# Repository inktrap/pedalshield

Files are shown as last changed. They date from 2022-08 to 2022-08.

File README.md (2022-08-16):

# Pedalshield Due

I wanted "my own" overview of pedalshield resources, one that allows for collaboration and forks, and that is always available. So here we go.

## General

 - [electrosmash site](https://www.electrosmash.com/pedalshield)
 - the [most important topics](https://www.electrosmash.com/forum/software-pedalshield/233-best-pedalshield-due-topics) from the [electrosmash due forum](https://www.electrosmash.com/forum/pedalshield-due)
 - [howtos](https://www.electrosmash.com/forum/hardware-pedalshield/20-how-to-build-pedalshield-in-5-steps?lang=en)  ([pdf](https://www.electrosmash.com/media/kunena/attachments/44/How-to-Build-pedalSHIELD-DUE.pdf), [flickr](https://www.flickr.com/photos/electrosmash/sets/72157638250771595/), [youtube](
https://www.youtube.com/watch?v=0nAO9C56jZM))

## Hardware

Analysis

 - [hardware analysis](https://www.electrosmash.com/forum/hardware-pedalshield/166-hardware-analysis-of-pedalshield)
 - [circuit diagram](https://i.stack.imgur.com/7KS3T.png) → `circuit.png`
 - [input/output stages](https://www.electrosmash.com/forum/hardware-pedalshield/73-input-output-stages)

Parts

 - [BOM](https://www.electrosmash.com/media/kunena/attachments/44/BOM-pedalSHIELD.rar) (rar) `BOM-pedalSHIELD.rar` → `bom` and [alternatives](https://www.electrosmash.com/forum/hardware-pedalshield/17-pedalshield-bill-of-materials-and-alternatives)
 - [best options to power arduino due](http://www.electrosmash.com/forum/hardware-pedalshield/26-powering-arduino-due?lang=en)
 - [troubleshooting guide](http://www.electrosmash.com/forum/hardware-pedalshield/72-guide-to-troubleshoot-pedalshield?lang=en)

Files

 - [kicad schematics](https://www.electrosmash.com/forum/hardware-pedalshield/18-kicad-schematics-pedalshield) via `PedalShield-rev.E-nativefiles.zip` → `kicad`
 - [gerber files](https://www.electrosmash.com/media/kunena/attachments/631/pedalSHIELDGerberFIles.rar) (rar) `pedalSHIELDGerberFIles.rar` → `gerber`
 - [pcb transfers](http://www.electrosmash.com/forum/hardware-pedalshield/82-pedalshield-pcb-transfers?lang=en)

## Software

 - [how to program pedalshield](http://www.electrosmash.com/forum/software-pedalshield/21-how-to-start-programming-pedalshield?lang=en)
 - effects: [bitcrusher](http://www.electrosmash.com/forum/software-pedalshield/156-bitcrusher-sample-rate-reducer-with-lfo?lang=en#592), [schroeder's reverb](http://www.electrosmash.com/forum/software-pedalshield/175-schoreder-s-reverb?lang=en), [Chorus, Chorus Dattorro, Echo, Flanger, Vibrato, Fuzz, Reverb Schroeder, Tremolo](http://www.electrosmash.com/forum/software-pedalshield/133-several-codes-based-on-pedalshield-library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) all by AndrewHPAvei
 - [all pedals](https://www.open-electronics.org/wp-content/uploads/2014/04/pedalSHIELD-all-pedals.rar) (rar) `pedalSHIELD-all-pedals.rar` → `pedals`

## Misc

 - [covers and cases on thingiverse](https://www.thingiverse.com/search?q=pedalshield&sa=&dwh=485aa2707f64633&type=things&sort=relevant), [printed cover](https://www.thingiverse.com/thing:210541) → `covers`. Laser cut covers are in the electrosmash shop as part of the kit.
 - [op amp book](http://www.ee.nmt.edu/~anders/courses/ee322s10/op-amp-slod006a.pdf) (pdf) `op-amp-slod006a.pdf`
 - connect a [screen](http://www.electrosmash.com/forum/hardware-pedalshield/94-mounting-an-oled-screen-on-my-pedalshield?lang=en), a [microphone](http://www.electrosmash.com/forum/hardware-pedalshield/39-connecting-a-microphone-to-pedalshield?lang=en), … also mods for a [bass guitar](http://www.electrosmash.com/forum/hardware-pedalshield/79-guitar-pedal-modification-pedalshield-for-bass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) … these are just copied from the [important topics](https://www.electrosmash.com/forum/software-pedalshield/233-best-pedalshield-due-topics) linked at the beginning.

# License

Published under the [Attribution-NonCommercial 3.0 Unported (CC BY-NC 3.0)](https://creativecommons.org/licenses/by-nc/3.0/) license. Some 
[rights are reserved](https://www.electrosmash.com/rights). Currently all of this can be found through [the links mentioned here](https://www.electrosmash.com/pedalshield) anyways.

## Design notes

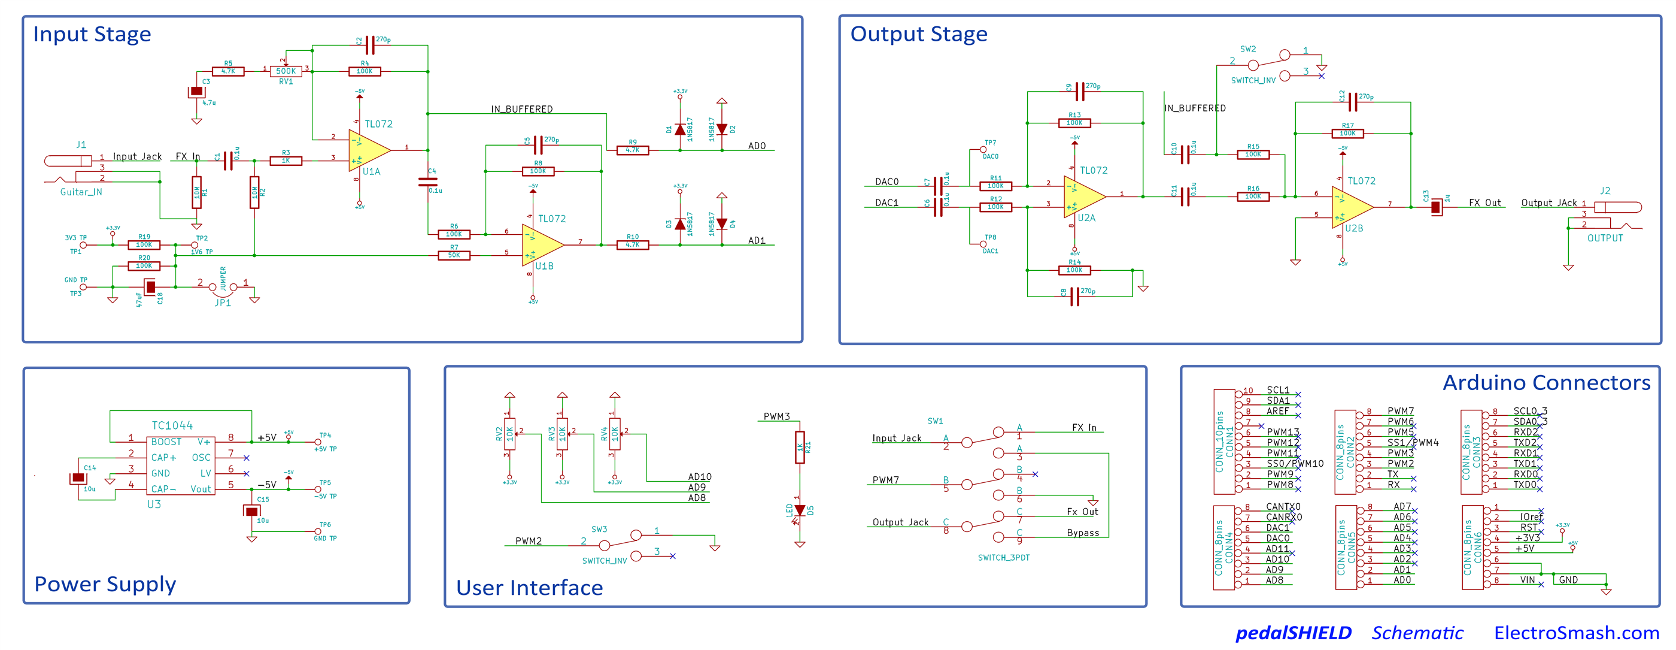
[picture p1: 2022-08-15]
circuit.png

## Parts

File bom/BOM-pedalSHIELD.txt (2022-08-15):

pedalSHIELD Bill of Materials / Part List.
 
Value		Qty		References					Description					Mouser Reference
Capacitors	 	 	 	 
270p		5		C2 C5 C8 C9 C12					Ceramic Disc Cap.				140-50S5-271J-RC
0.1u		6		C1 C4 C6 C7 C10 C11				Film Capacitors.				ECQ-V1H104JL
1u		1		C13						Aluminium Electrolytic Capacitors 		ECE-A1HKA010
4.7u		1		C3						Aluminium Electrolytic Capacitors 		ECE-A1EKA4R7
10u		2		C14 C15						Aluminium Electrolytic Capacitors 		ECE-A1HKA100B
47uF		1		C18						Aluminium Electrolytic Capacitors 		REA470M1CBK-0511P
Resistors	 	 	 
1K		2		R3 R21						Metal Film Resistors, 1% Tol.			MF1/4DC1001F
4.7K		3		R5 R9 R10 					Metal Film Resistors, 1% Tol.			MF1/4DCT52R4701F
50K		1		R7						Metal Film Resistors, 1% Tol.			MF1/4DCT52R4992F
100K		12		R4 R6 R8 R11 R12 R13 R14 R15 R16 R17 R19 R20	Metal Film Resistors, 1% Tol.			MF1/4DCT52R1003F
10M		2		R1 R2						Metal Film Resistors, 1% Tol.			RK1/4DC1005F
500K		1		RV1						Trimmer Resistors - 9mm Single Turn		3319W-3-504
10K		3		RV2 RV3 RV4					Alpha Potentiometers Flat 20mm			RK09L114001T
Knobs		3		RV2, RV3, RV4					Plastic Knob with screw, Shaft:6.35mm		450-2023-GRX
Others	 	 	 	 
1N5817		4		D1 D2 D3 D4					Schottky Diodes Vr/20V Io/1A 			1N5817
LED		1		D5						Through hole, blue led.				C4SMG-BJS-CQ0T0451
SWITCH_3PDT	1		SW1						3PDT True Bypass Footswitch 			107-SF17020F-32-21RL
SWITCH_INV	2		SW2 SW3						Toggle Switch SPDT				612-100-A1111
Connectors	 	 	 	 
CONN_8pins	5		CONN2 CONN3 CONN4 CONN5 CONN6  			40pins stripe 
JACKS		2		JI, J2						Neutrix 1/4 stereo Chrome Phone Conn.		NMJ6HCD2
IC's	 	 	 	 
TL072		2		U1 U2						Operational amplifier.				TL072IPE4
TC1044		1		U3						Voltage switching regulator. 			TC1044SCPA
8PINSOCKETS	3		U1, U2, U3					8pin DIP plastic socket.			1-390261-2
Mechanic	 	 	 	 
pedalSHIELD PCB	1								Dual Layer 2x4” PCB with soldermask.	 
Plastic Cover	1								3D printed plastic cover protector.

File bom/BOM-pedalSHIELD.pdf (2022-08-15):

Sheet1

Page 1

Value

270p | 5 C2 C5 C8 C9 C12 | 140-50S5-271J-RC
0.1u | 6 C1 C4 C6 C7 C10 C11 | ECQ-V1H104JL
1u | 1 C13 | ECE-A1HKA010
4.7u | 1 C3 | ECE-A1EKA4R7
10u | 2 C14 C15 | ECE-A1HKA100B
47uF | 1 C18 | REA470M1CBK-0511P
1K | 2 R3 R21 | MF1/4DC1001F
4.7K | 3 R5 R9 R10 | MF1/4DCT52R4701F
50K | 1 R7 | MF1/4DCT52R4992F
100K | 12 R4 R6 R8 R11 R12 R13 R14 R15 R16 R17 R19 R20 | MF1/4DCT52R1003F
10M | 2 R1 R2 | RK1/4DC1005F
500K | 1 RV1 | 3319W-3-504
10K | 3 RV2 RV3 RV4 | RK09L114001T
| 3 RV2, RV3, RV4 | 450-2023-GRX
1N5817 | 4 D1 D2 D3 D4 | 1N5817
LED | 1 D5 | C4SMG-BJS-CQ0T0451
SWITCH_3PDT | 1 SW1 | 107-SF17020F-32-21RL
SWITCH_INV | 2 SW2 SW3 | 612-100-A1111
CONN_8pins | 5 CONN2 CONN3 CONN4 CONN5 CONN6
JACKS | 2 JI, J2 | NMJ6HCD2
TL072 | 2 U1 U2 | TL072IPE4
TC1044 | 1 U3 | TC1044SCPA
8PIN SOCKETS | 3 U1, U2, U3 | 1-390261-2
| 1
| 1

pedalSHIELD Bill of Materials /Parts List

Qty | References | Description | Mouser Reference
Capacitors
| | Ceramic Disc Capacitors
Film Capacitors.
| | Aluminium Electrolytic Capacitors Aluminium Electrolytic Capacitors Aluminium Electrolytic Capacitors Aluminium Electrolytic Capacitors

Resistors
| | Metal Film Resistors, 1% Tol. Metal Film Resistors, 1% Tol. Metal Film Resistors, 1% Tol. Metal Film Resistors, 1% Tol. Metal Film Resistors, 1% Tol. Trimmer Resistors - 9mm Single Turn Alpha Potentiometers Flat 20mm
Plastic Knobs | Plastic Knob with screw, Shaft:6.35mm
Others
| | Schottky Diodes Vr/20V Io/1A Through hole, blue led. 3PDT True Bypass Footswitch Toggle Switch SPDT

Connectors

| | Neutrix 1/4 stereo Chrome Phone Conn.
IC's
| | Operational amplifier. Voltage switching regulator. 8pin DIP plastic socket.

Mechanic
pedalSHIELD PCB | Dual Layer 2x4” PCB with soldermask.
Plastic Protector | 3D printed plastic cover protector.

Sheet1

Page 2

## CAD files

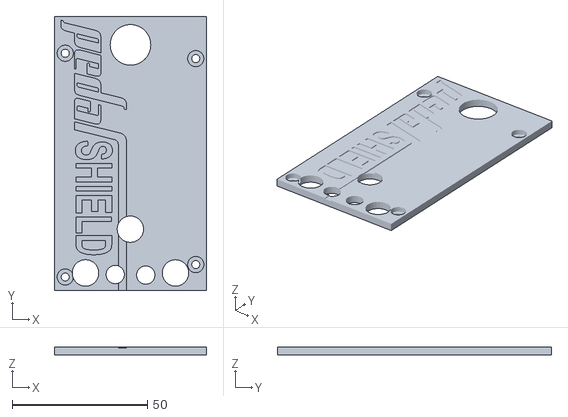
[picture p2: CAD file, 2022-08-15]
covers/shuttl3d/files/pedalSHIELD_a.stl
56.3 x 101.4 x 3.00

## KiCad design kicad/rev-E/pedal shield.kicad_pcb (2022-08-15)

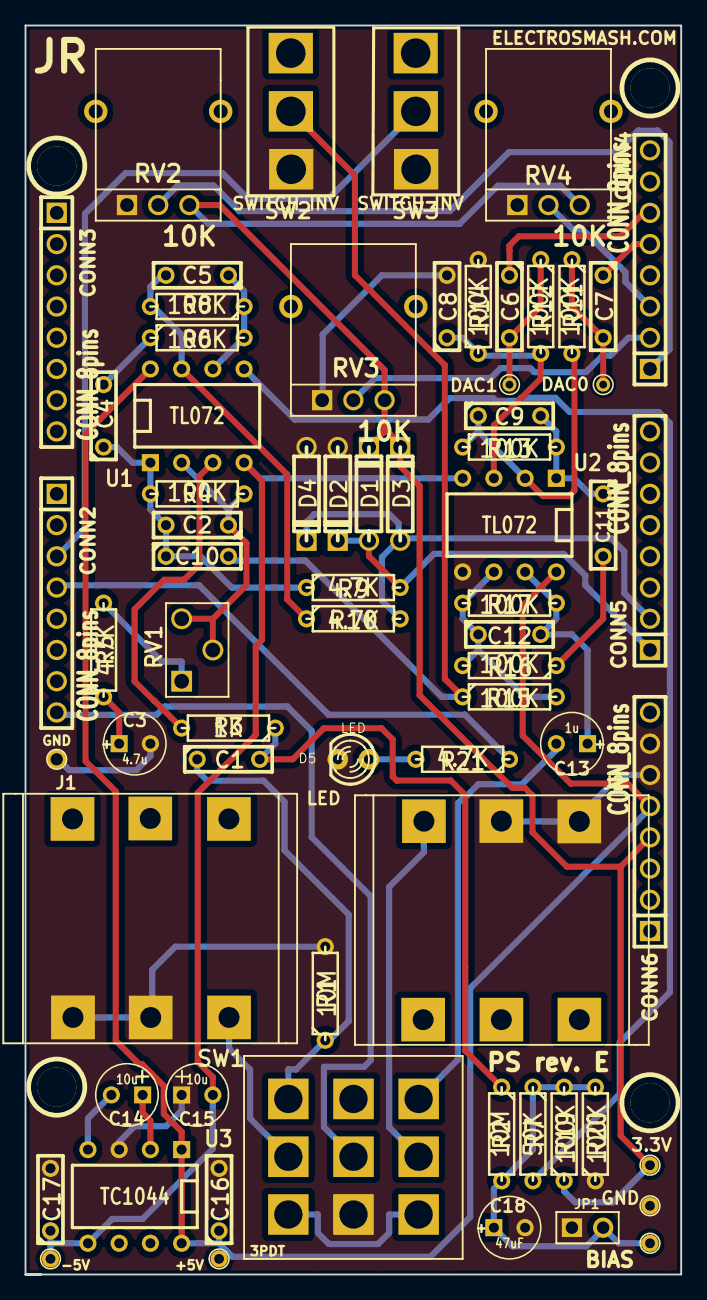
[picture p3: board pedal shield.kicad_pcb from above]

Board: 2 copper layers, 53.3 x 101.6 mm, 73 parts (0 on the bottom side), 42 nets.

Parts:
C1, C4, C6, C7, C10, C11: 0.1u; C2
C2, C5, C8, C9, C12: 47p; C2
C3: 4.7u; C1V5
C13: 1u; C1V5
C14, C15: 10u; C1V5
C16, C17: 100n; C2
C18: 47uF; C1V5
CONN2, CONN3, CONN4, CONN5, CONN6: CONN_8pins; SIL-8
D1, D2, D3, D4: 1N5817; D3
D5: LED; LED-3MM
J1: Guitar_IN; JACK_AUDIO
J2: OUTPUT; JACK_AUDIO
JP1: JUMPER; PIN_ARRAY_2X1
R1, R2: 10M; R3
R3: 1K; R3
R4, R6, R8, R11, R12, R13, R14, R15, R16, R17, R19, R20: 100K; R3
R5, R9, R10, R21: 4.7K; R3
R7: 50K; R3
RV1: 500K; PIN_ARRAY_3X1
RV2, RV3, RV4: 10K; RVAR
SW1: SWITCH_3PDT; 3PDT
SW2: SWITCH_INV; SW_SPDT_pedalSHIELD
SW3: SWITCH_INV; SW_SPDT
TP1: 3V3 TP; PINTST
TP2: 1V6 TP; PINTST
TP3, TP6: GND TP; PINTST
TP4: +5V TP; PINTST
TP5: -5V TP; PINTST
TP7: DAC0; PINTST
TP8: DAC1; PINTST
U1, U2: TL072; DIP-8__300
U3: TC1044; DIP-8__300
hole1: hole1; 1pin
hole2, hole3, hole4: P***; 1pin

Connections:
+3.3V: CONN6.4, D1.2, D3.2, R19.1, RV2.3, RV3.3, RV4.3, TP1.1
+5V: C16.1, CONN6.5, TP4.1, U1.8, U2.8, U3.1, U3.8
-5V: C15.1, C17.1, TP5.1, U1.4, U2.4, U3.5
/AD0: CONN5.1, D1.1, D2.2, R9.2
/AD1: CONN5.2, D3.1, D4.2, R10.2
/AD8: CONN4.1, RV2.2
/AD9: CONN4.2, RV3.2
/AD10: CONN4.3, RV4.2
/Bypass: SW1.3, SW1.9
/DAC0: C7.1, CONN4.5
/DAC1: C6.1, CONN4.6
/FX In: C1.1, R1.1, SW1.1
/FX Out: C13.2, SW1.7
/IN_BUFFERED: C2.2, C4.1, C10.1, R4.2, R9.1, U1.1
/Input Jack: J1.1, SW1.2
/Output JAck: J2.1, SW1.8
/PWM2: CONN2.3, SW3.2
/PWM3: CONN2.4, R21.1
/PWM7: CONN2.8, SW1.5
GND: C3.2, C8.2, C15.2, C16.2, C17.2, C18.2, CONN6.6, CONN6.7, D2.1, D4.1, D5.2, J1.2, J1.3, J2.2, J2.3, JP1.1, R1.2, R14.2, R20.1, RV2.1, RV3.1, RV4.1, SW1.6, SW2.1, SW3.1, TP3.1, TP6.1, U2.5, U3.3
unnamed: D5.1, R21.2
unnamed: C18.1, JP1.2, R2.2, R7.1, R19.2, R20.2, TP2.1
unnamed: C2.1, R4.1, RV1.2, RV1.3, U1.2
unnamed: C3.1, R5.1
unnamed: R5.2, RV1.1
unnamed: C9.2, C11.1, R13.2, U2.1
unnamed: C12.2, C13.1, R17.2, U2.7
unnamed: C11.2, R16.1
unnamed: C8.1, R12.2, R14.1, U2.3
unnamed: C12.1, R15.2, R16.2, R17.1, U2.6
unnamed: C14.2, U3.4
unnamed: C14.1, U3.2
unnamed: R7.2, U1.5
unnamed: C10.2, R15.1, SW2.2
unnamed: C7.2, R11.1, TP7.1
unnamed: C6.2, R12.1, TP8.1
unnamed: C5.2, R8.2, R10.1, U1.7
unnamed: C5.1, R6.2, R8.1, U1.6
unnamed: C4.2, R6.1
unnamed: R3.2, U1.3
unnamed: C1.2, R2.1, R3.1
unnamed: C9.1, R11.2, R13.1, U2.2

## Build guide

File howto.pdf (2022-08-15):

www.electrosmash.com/pedalshield-uno
How to Build pedalSHIELD UNO
This is a 5 steps guide to build pedalSHIELD UNO. With all the materials on hand it takes around 2-3 hours to build it successfully. Take your time to double check every step and enjoy!
Step 0 – Prepare the Materials.
You need a solder iron, lead and cutting pliers. Additionally cutter, scissors and pliers are convenient. The PCB has solder mask and plated holes, so it is easy to solder with any 15-30W cheap solder iron.

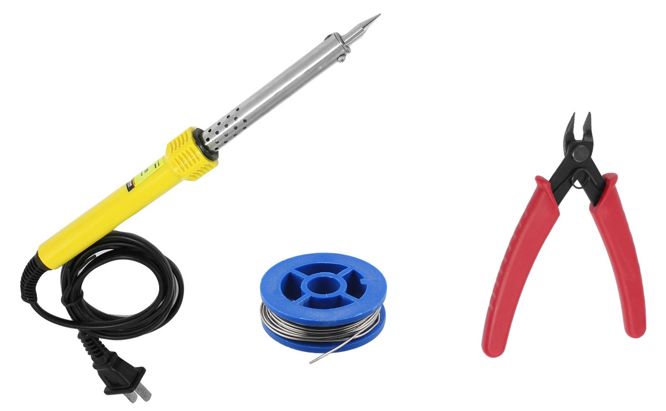
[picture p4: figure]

Keep in short hand the PCB plan and the Bill of Materials:
Reference | Value

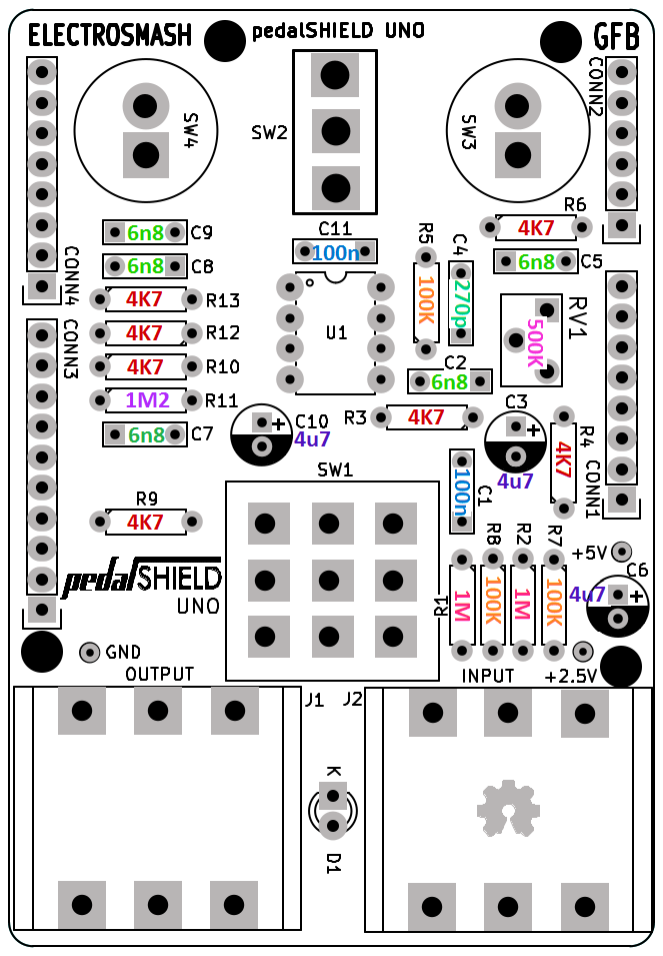
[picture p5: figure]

C2,C5, C7, C8, C9 | 5 6.8n
C3, C6, C10 | 3 4.7u
C1, C11 | 2 100n
C4 | 1 270p

R12,R13, R10, R9, R6, R4, R3 7 4.7K
R5, R7, R8 | 3 100K
R1, R2 | 2 1M
R11 | 1 1M2
RV1 | 1 500K
D1 | 1 Led 3mm blue
U1 | 1
socket | 1 dip 8 socket
SW1 | 1
SW2 | 1 Toggle switch
SW3, SW4 | 2
Conn1,2,3,4 | 1 40 pin header
J1, J2 | 2 1/4 Jack audio

Qty
Capacitors

Resistors

Others

TL972 pdip-8

3DPT footswitch

Pushbutton

Step 1 – Soldering Resistors. There are 13 resistors to be placed:

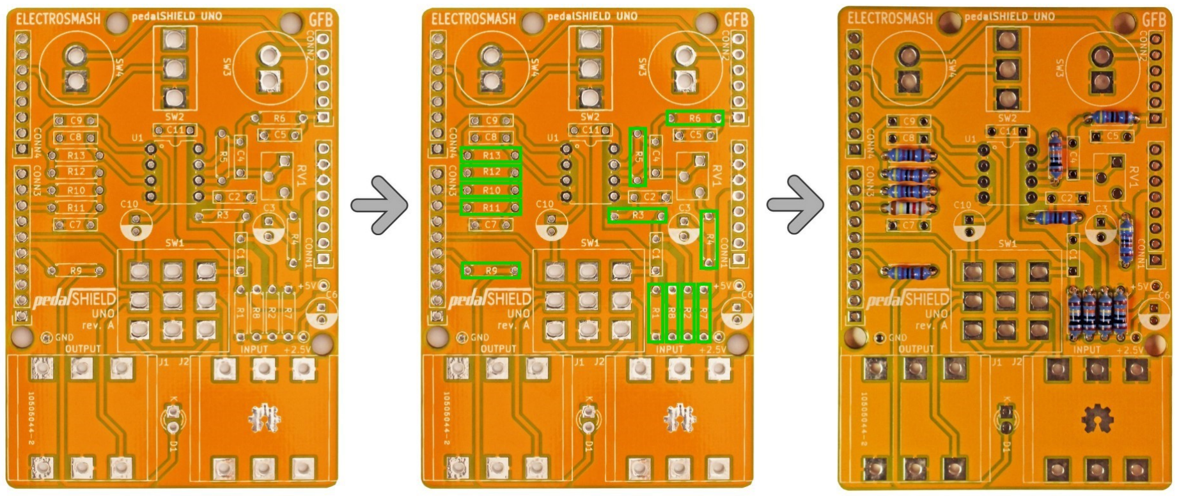
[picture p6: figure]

- Solder the 4.7KΩ resistors (7 units): R3, R4, R6, R9, R10, R12, R13.
- Solder the 100KΩ resistors (3 units): R5, R7, R8.
- Solder the 1M resistors (2 units): R1, R2.
- Solder the 1.2M resistor: R11.

tips:
- In order to solder the components, bend the leads close to the body, introduce them in the footprint and once soldered cut the excess of lead as short as possible to avoid short circuits.
There is a nice video on Youtube (https://www.youtube.com/watch?v=f95i88OSWB4) to learn how to solder from scratch.

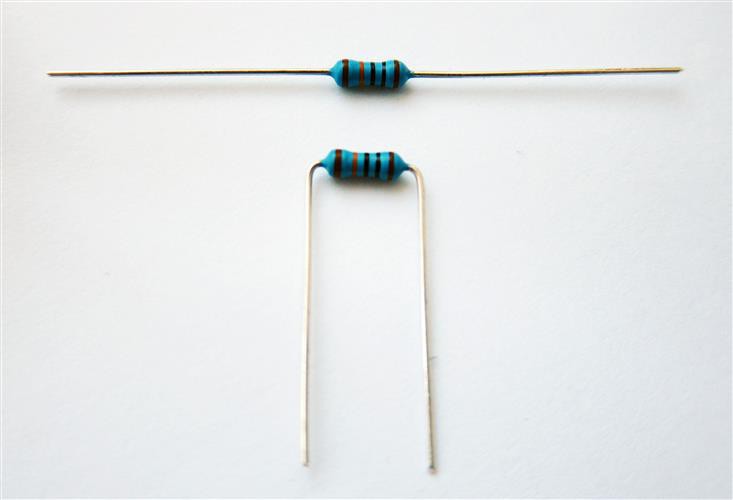
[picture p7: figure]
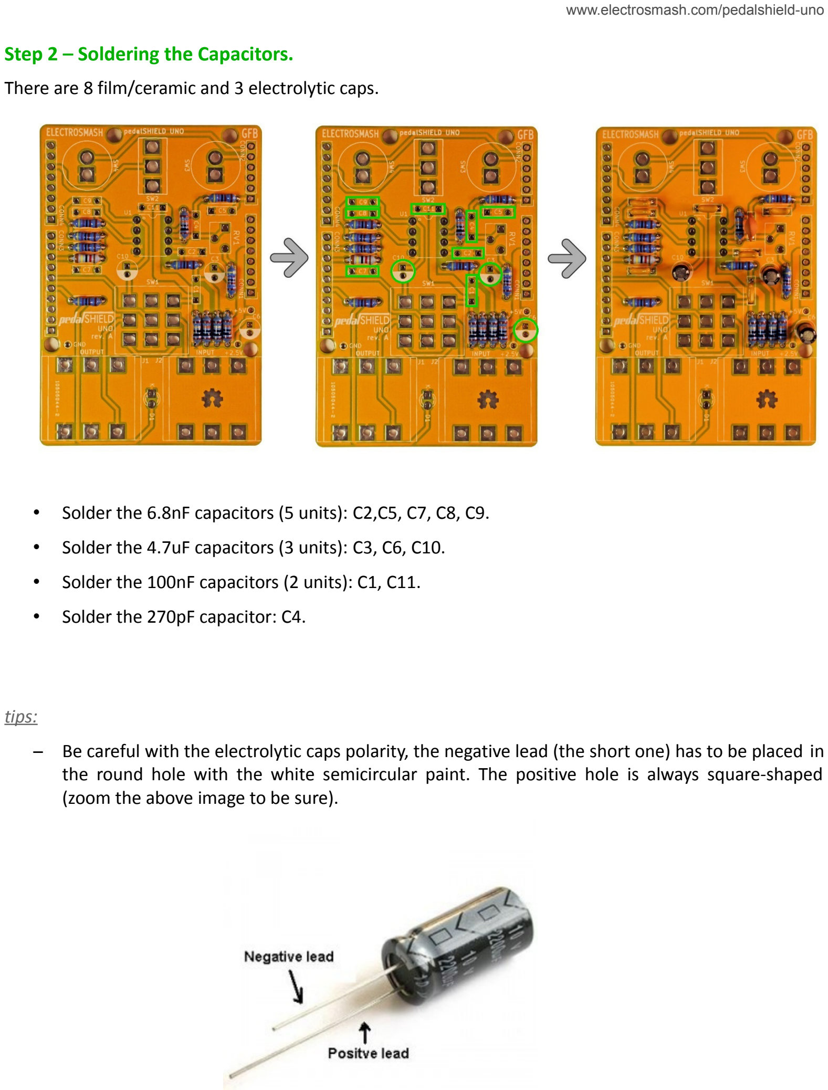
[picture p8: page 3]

Step 2 – Soldering the Capacitors.
There are 8 film/ceramic and 3 electrolytic caps.
- Solder the 6.8nF capacitors (5 units): C2,C5, C7, C8, C9.
- Solder the 4.7uF capacitors (3 units): C3, C6, C10.
- Solder the 100nF capacitors (2 units): C1, C11.
- Solder the 270pF capacitor: C4.

tips:
– Be careful with the electrolytic caps polarity, the negative lead (the short one) has to be placed in the round hole with the white semicircular paint. The positive hole is always square-shaped (zoom the above image to be sure).

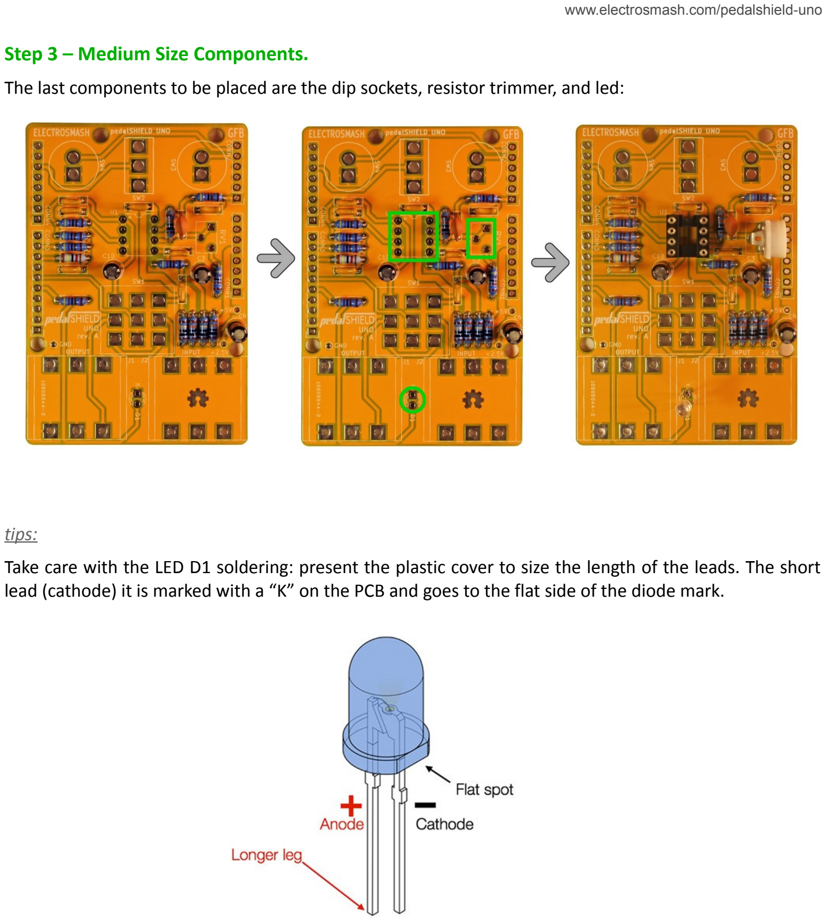
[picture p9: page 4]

Step 3 – Medium Size Components.
The last components to be placed are the dip sockets, resistor trimmer, and led:

tips:
Take care with the LED D1 soldering: present the plastic cover to size the length of the leads. The short lead (cathode) it is marked with a “K” on the PCB and goes to the flat side of the diode mark.

Step 4 – Soldering the Big Components.
The last components to be placed are the push-buttons (2), toggle switch (1), 3PDT Foot-switch (1) and jack connectors (2) and the pin stripes:

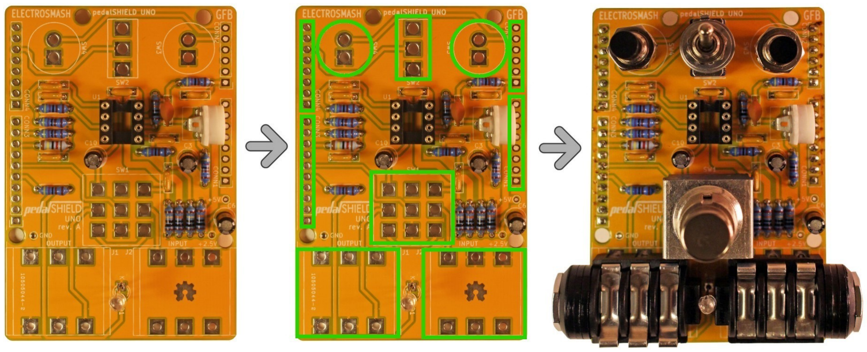
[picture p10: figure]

tips:

- When soldering the potentiometers and switches it would be good to check their positioning against the plastic cover. The cover will fit better if the cover its aligned.
- Be careful soldering the big components perpendicularly because they tend to be slightly tilted.

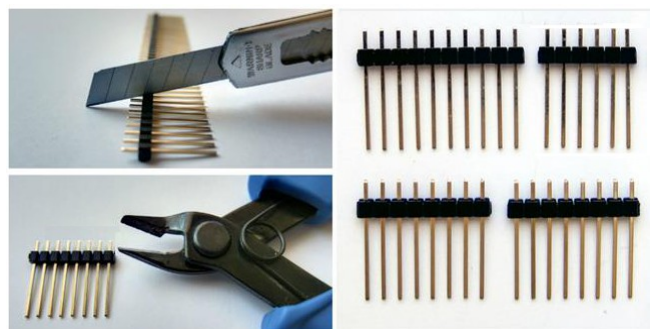
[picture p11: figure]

- The 40 pin stripe has to be cut in 4 segments of 6 pins, 8 pins, 8 pins and 10 pins each.
You can use a cutter to carve a groove and then just bend it carefully to break it. Wire-cutters also work fine.

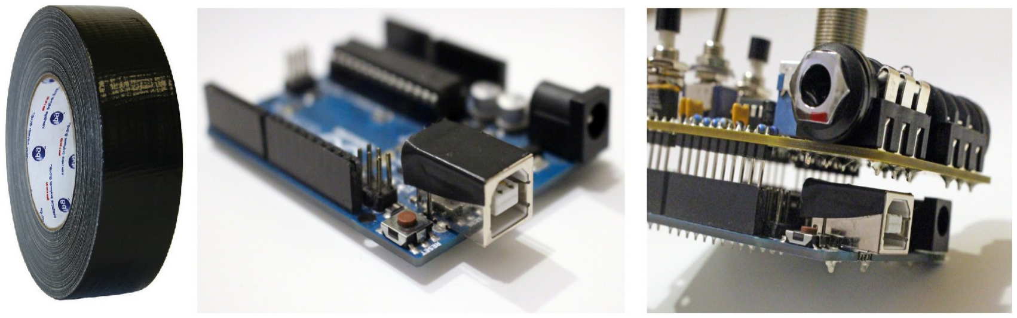
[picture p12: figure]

-The USB
connector is too
close to the output
jack, to avoid short
circuits isolate the
USB jack with some
duck tape.

Step 5 – Checking Out the Job Done.
After this 5 stages you will have a mounted board exactly like the one shown below:

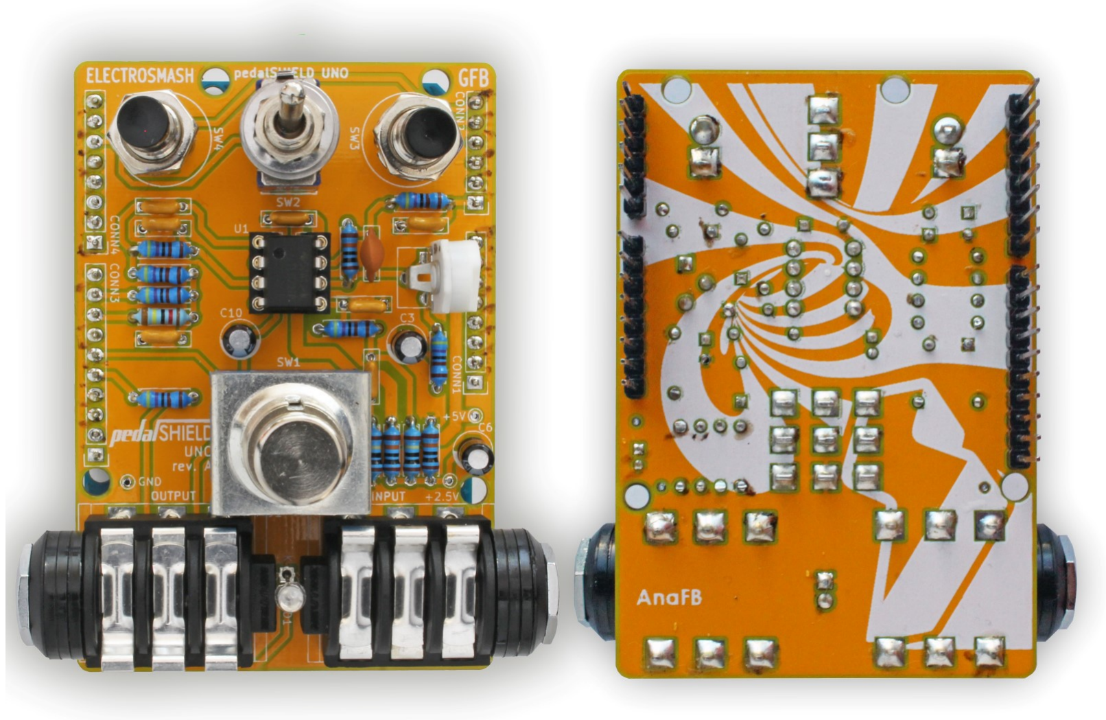
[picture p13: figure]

Double check your PCB with the model component by component.
Before power it up, check this 3 ticks:
☑ 1. Visual inspection of the PCB bottom, there is no short circuits or long uncut leads. ☑ 2. The polarized components are placed correctly: the diode and electrolytic caps.
☑ 3. The op-amp is placed right (not upside down).

If you need more help there is a topic in the forum called Guide to troubleshoot pedalSHIELD UNO. (http://electrosmash.com/forum/pedalshield-uno/135-how-to-troubleshoot-pedalshield-uno)

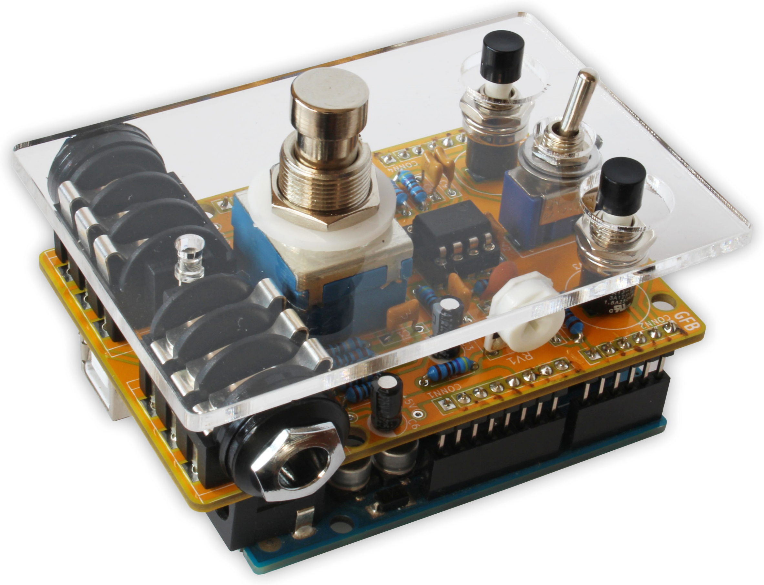
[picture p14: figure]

Finally the plastic cover can be placed, it is kept in placed by the foot-switch nut and plastic washer, simple and neat.

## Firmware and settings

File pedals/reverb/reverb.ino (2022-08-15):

// Licensed under a Creative Commons Attribution 3.0 Unported License.
// Based on rcarduino.blogspot.com previous work.
// www.electrosmash.com/pedalshield

/* reverb.ino creates two copies of the guitar signal to be delayed independently producing
  a reverb-like sound, the toggle switch selects between delaying or echoing the signals*/
  
int in_ADC0, in_ADC1;  //variables for 2 ADCs values (ADC0, ADC1)
int POT0, POT1, POT2, out_DAC0, out_DAC1; //variables for 3 pots (ADC8, ADC9, ADC10)
int LED = 3;
int FOOTSWITCH = 7; 
int TOGGLE = 2; 
 
#define MAX_DELAY_A 20000
#define MAX_DELAY_B 20000
uint16_t DelayBuffer_A[MAX_DELAY_A];
uint16_t DelayBuffer_B[MAX_DELAY_B];
unsigned int DelayCounter_A = 0;
unsigned int DelayCounter_B = 0;
unsigned int Delay_Depth_A, Delay_Depth_B;
 
void setup()
{
  //turn on the timer clock in the power management controller
  pmc_set_writeprotect(false);
  pmc_enable_periph_clk(ID_TC4);
 
  //we want wavesel 01 with RC 
  TC_Configure(TC1,1, TC_CMR_WAVE | TC_CMR_WAVSEL_UP_RC | TC_CMR_TCCLKS_TIMER_CLOCK2);
  TC_SetRC(TC1, 1, 238); // sets <> 44.1 Khz interrupt rate
  TC_Start(TC1, 1);
 
  // enable timer interrupts on the timer
  TC1->TC_CHANNEL[1].TC_IER=TC_IER_CPCS;
  TC1->TC_CHANNEL[1].TC_IDR=~TC_IER_CPCS;
 
  //Enable the interrupt in the nested vector interrupt controller 
  //TC4_IRQn where 4 is the timer number * timer channels (3) + the channel number 
  //(=(1*3)+1) for timer1 channel1 
  NVIC_EnableIRQ(TC4_IRQn);
 
  //ADC Configuration
  ADC->ADC_MR |= 0x80;   // DAC in free running mode.
  ADC->ADC_CR=2;         // Starts ADC conversion.
  ADC->ADC_CHER=0x1CC0;  // Enable ADC channels 0,1,8,9 and 10  
 
  //DAC Configuration
  analogWrite(DAC0,0);  // Enables DAC0
  analogWrite(DAC1,0);  // Enables DAC0
 
  //Pin Configuration
  pinMode(LED, OUTPUT);  
  pinMode(FOOTSWITCH, INPUT);     
  pinMode(TOGGLE, INPUT);     
}
 
void loop()
{
  //Read the ADCs
  while((ADC->ADC_ISR & 0x1CC0)!=0x1CC0);// wait for ADC 0, 1, 8, 9, 10 conversion complete.
  in_ADC0=ADC->ADC_CDR[7];           // read data from ADC0
  in_ADC1=ADC->ADC_CDR[6];           // read data from ADC1  
  POT0=ADC->ADC_CDR[10];                // read data from ADC8        
  POT1=ADC->ADC_CDR[11];                // read data from ADC9   
  POT2=ADC->ADC_CDR[12];                // read data from ADC10     
}
 
void TC4_Handler() //Interrupt at 44.1KHz rate (every 22.6us)
{
  //Clear status allowing the interrupt to be fired again.
  TC_GetStatus(TC1, 1);
 
    //Check the TOGGLE SWITCH and select between super-reverb and reverb.
    if (digitalRead(TOGGLE))
  { 
     //Store current readings in ECHO mode
     DelayBuffer_A[DelayCounter_A]=(in_ADC0 + (DelayBuffer_A[DelayCounter_A]))>>1;
     DelayBuffer_B[DelayCounter_B]=(in_ADC1 + (DelayBuffer_B[DelayCounter_B]))>>1; 
     digitalWrite(LED, HIGH); 
  }
 
    else 
  {
     //Store current readings in DELAY mode  
     DelayBuffer_A[DelayCounter_A]  = in_ADC0 ;
     DelayBuffer_B[DelayCounter_B]  = in_ADC1 ;  
     digitalWrite(LED, LOW);
  }
 
  //Adjust Delay Depth based in POT0 and POT1 position.
  Delay_Depth_A =map(POT0>>3,0,512,1,MAX_DELAY_A);
  Delay_Depth_B =map(POT1>>3,0,512,1,MAX_DELAY_B);
 
  //Increse/reset delay counter.   
  DelayCounter_A++;
  DelayCounter_B++;
  if(DelayCounter_A >= Delay_Depth_A) DelayCounter_A = 0; 
  if(DelayCounter_B >= Delay_Depth_B) DelayCounter_B = 0; 
 
  //Calculate the output as the sum of DelayBuffer_A + DelayBuffer_B 
  out_DAC0 = (DelayBuffer_A[DelayCounter_A]);
  out_DAC1 = (DelayBuffer_B[DelayCounter_B]);
 
  //Add volume feature based in pot2 position.
  out_DAC0=map(out_DAC0,0,4095,1,POT2);
  out_DAC1=map(out_DAC1,0,4095,1,POT2);
 
  //Write the DACs
  dacc_set_channel_selection(DACC_INTERFACE, 0);       //select DAC channel 0
  dacc_write_conversion_data(DACC_INTERFACE, out_DAC0);//write on DAC
  dacc_set_channel_selection(DACC_INTERFACE, 1);       //select DAC channel 1
  dacc_write_conversion_data(DACC_INTERFACE, out_DAC1);//write on DAC
}
